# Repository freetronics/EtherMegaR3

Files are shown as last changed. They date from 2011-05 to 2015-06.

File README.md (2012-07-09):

Freetronics EtherMega R3
========================
Copyright 2011-2012 Freetronics Pty Ltd  
Freetronics site:  www.freetronics.com  
Freetronics email: info@freetronics.com  

The EtherMega R3 is a 100% Arduino-compatible board based on the existing
Mega2560, but with improvements and updates for features and ease of
use. It also includes on-board Ethernet with PoE (Power-over-Ethernet)
support.

Features:

 * High-efficiency switchmode power supply (input voltage 7-28Vdc)
 * Micro-USB Connector
 * microSD card slot
 * 10/100 Ethernet using the Wiznet W5100 chip
 * Overlay guide where you need it (both top and bottom)
 * D13 pin works for everything

You can view more at our product page at:

  http://www.freetronics.com/ethermega

INSTALLATION
------------
The design is saved as an EAGLE project. EAGLE PCB design software is
available from www.cadsoftusa.com free for non-commercial use. To use
this project download it and place the directory containing these files
into the "eagle" directory on your computer. Then open EAGLE and
navigate to Projects -> eagle -> EtherMegaR3.

DISTRIBUTION
------------
The specific terms of distribution of this project are governed by the
license referenced below.

LICENSE
-------
This work is licensed under the
Creative Commons Attribution-Share Alike License.  
To view a copy of this license, visit

  http://creativecommons.org/licenses/by-sa/3.0/  
  http://creativecommons.org/licenses/by-sa/3.0/legalcode

or send a letter to

  Creative Commons  
  171 Second Street, Suite 300  
  San Francisco  
  California, 94105  
  USA

The "license" folder within this repository also contains copies of the
licences referenced above.

CREDITS
-------
The EtherMega was designed by Marc Alexander (marc@freetronics.com) and
Jonathan Oxer (jon@freetronics.com) based on previous work by the Arduino
team (www.arduino.cc/playground/Main/People) which includes:

 * Massimo Banzi
 * David Cuartielles
 * Tom Igoe
 * Gianluca Martino
 * David A. Mellis

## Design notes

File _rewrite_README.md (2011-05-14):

Freetronics EtherTen
====================
Copyright 2010 Freetronics Pty Ltd  
Freetronics site:  <www.freetronics.com>  
Freetronics email: <info@freetronics.com>  

The EtherTen is a 100% Arduino Compatible Board, based on the existing
Duemilanove, but with improvements and updates for ease of use, cost
and getting started. It also includes on-board Ethernet with PoE (Power
-over-Ethernet) support.

Features:

 * LEDs visible on the edge
 * Mini-USB Connector
 * Overlay guide where you need it (both top and bottom)
 * D13 pin works for everything
 * RX pin biased
 * Mounting holes, power and X3 pads
 * All connections in the same place

You can view more at our product page at:

  http://www.freetronics.com/etherten

The "docs" folder within this repository includes a handy copy of the
schematic in PDF format, images of the pcb, and our Getting Started
guide that ships with each board.

INSTALLATION
------------
The design is saved as an EAGLE project. EAGLE PCB design software is
available from www.cadsoftusa.com free for non-commercial use. To use
this project download it and place the directory containing these files
into the "eagle" directory on your computer. Then open EAGLE and
navigate to Projects -> eagle -> EtherTen.

DISTRIBUTION
------------
The specific terms of distribution of this project are governed by the
license referenced below.

LICENSE
-------
This work is licensed under the
Creative Commons Attribution-Share Alike License.  
To view a copy of this license, visit

  http://creativecommons.org/licenses/by-sa/3.0/  
  http://creativecommons.org/licenses/by-sa/3.0/legalcode

or send a letter to

  Creative Commons  
  171 Second Street, Suite 300  
  San Francisco  
  California, 94105  
  USA

The "license" folder within this repository also contains copies of the
licences referenced above.

CREDITS
-------
The EtherTen was designed by Marc Alexander (marc@freetronics.com)
based on previous work by the Arduino team
(www.arduino.cc/playground/Main/People) which includes:

 * Massimo Banzi
 * David Cuartielles
 * Tom Igoe
 * Gianluca Martino
 * David A. Mellis

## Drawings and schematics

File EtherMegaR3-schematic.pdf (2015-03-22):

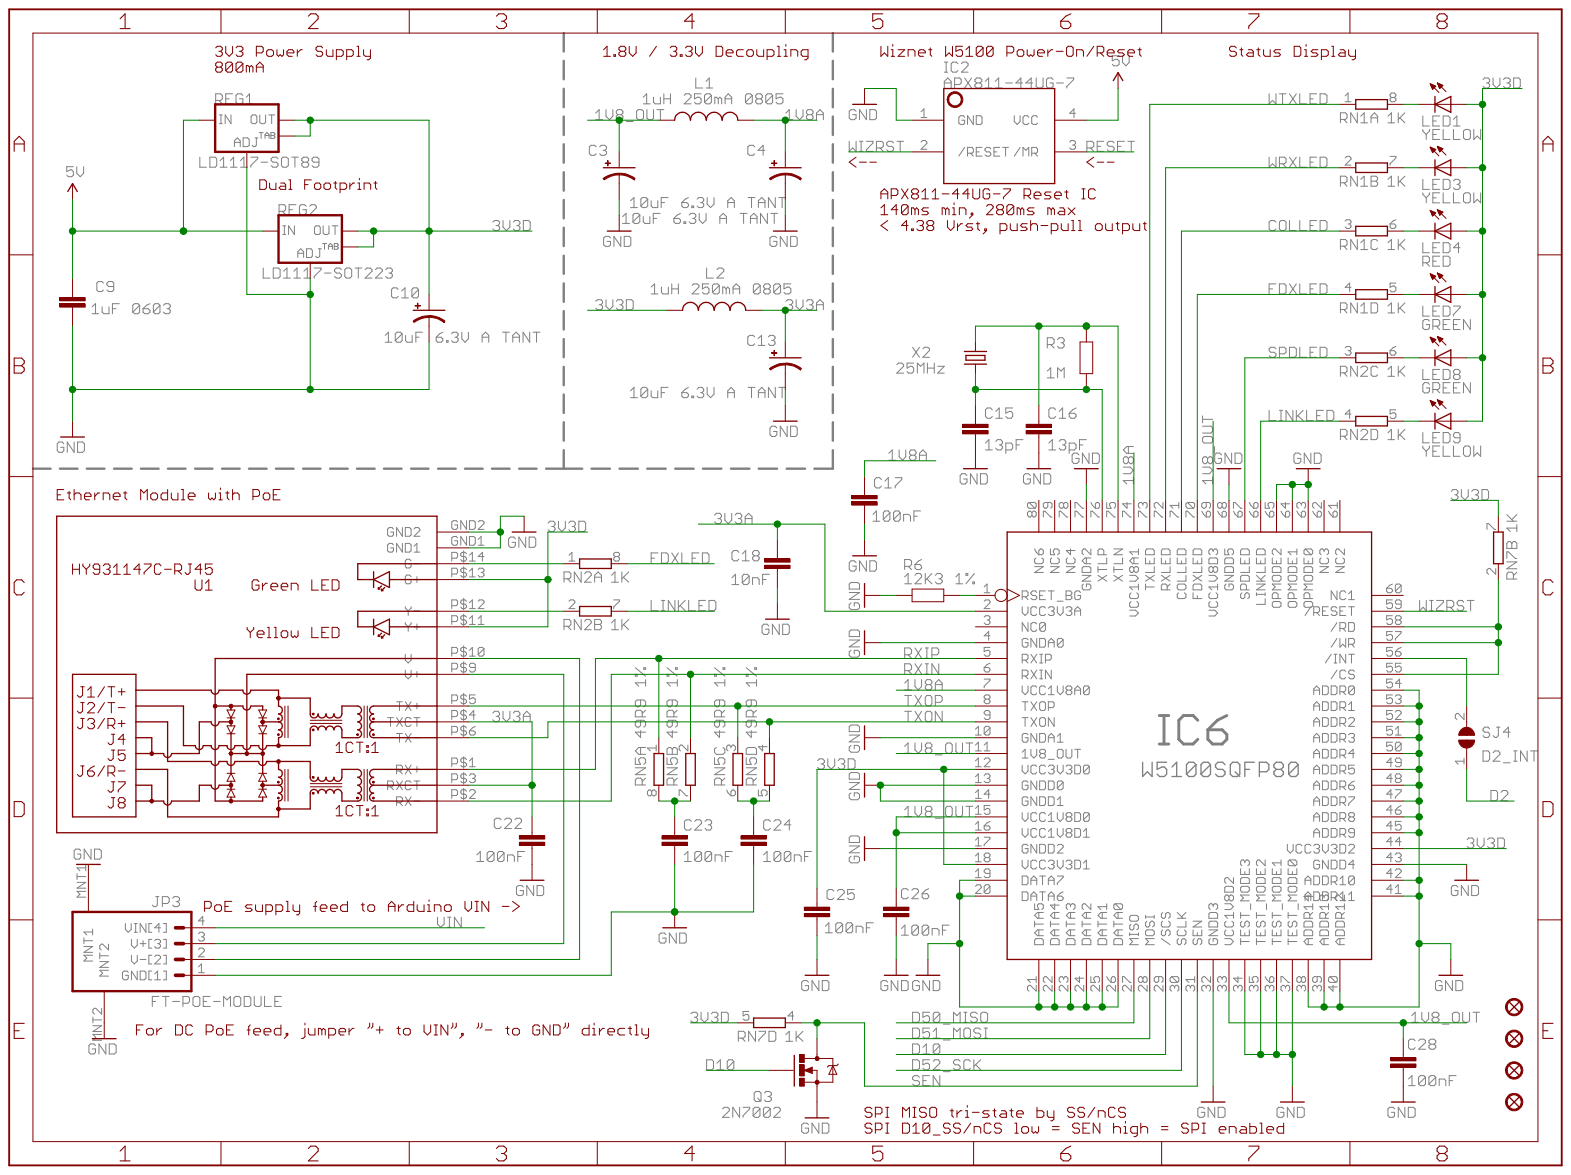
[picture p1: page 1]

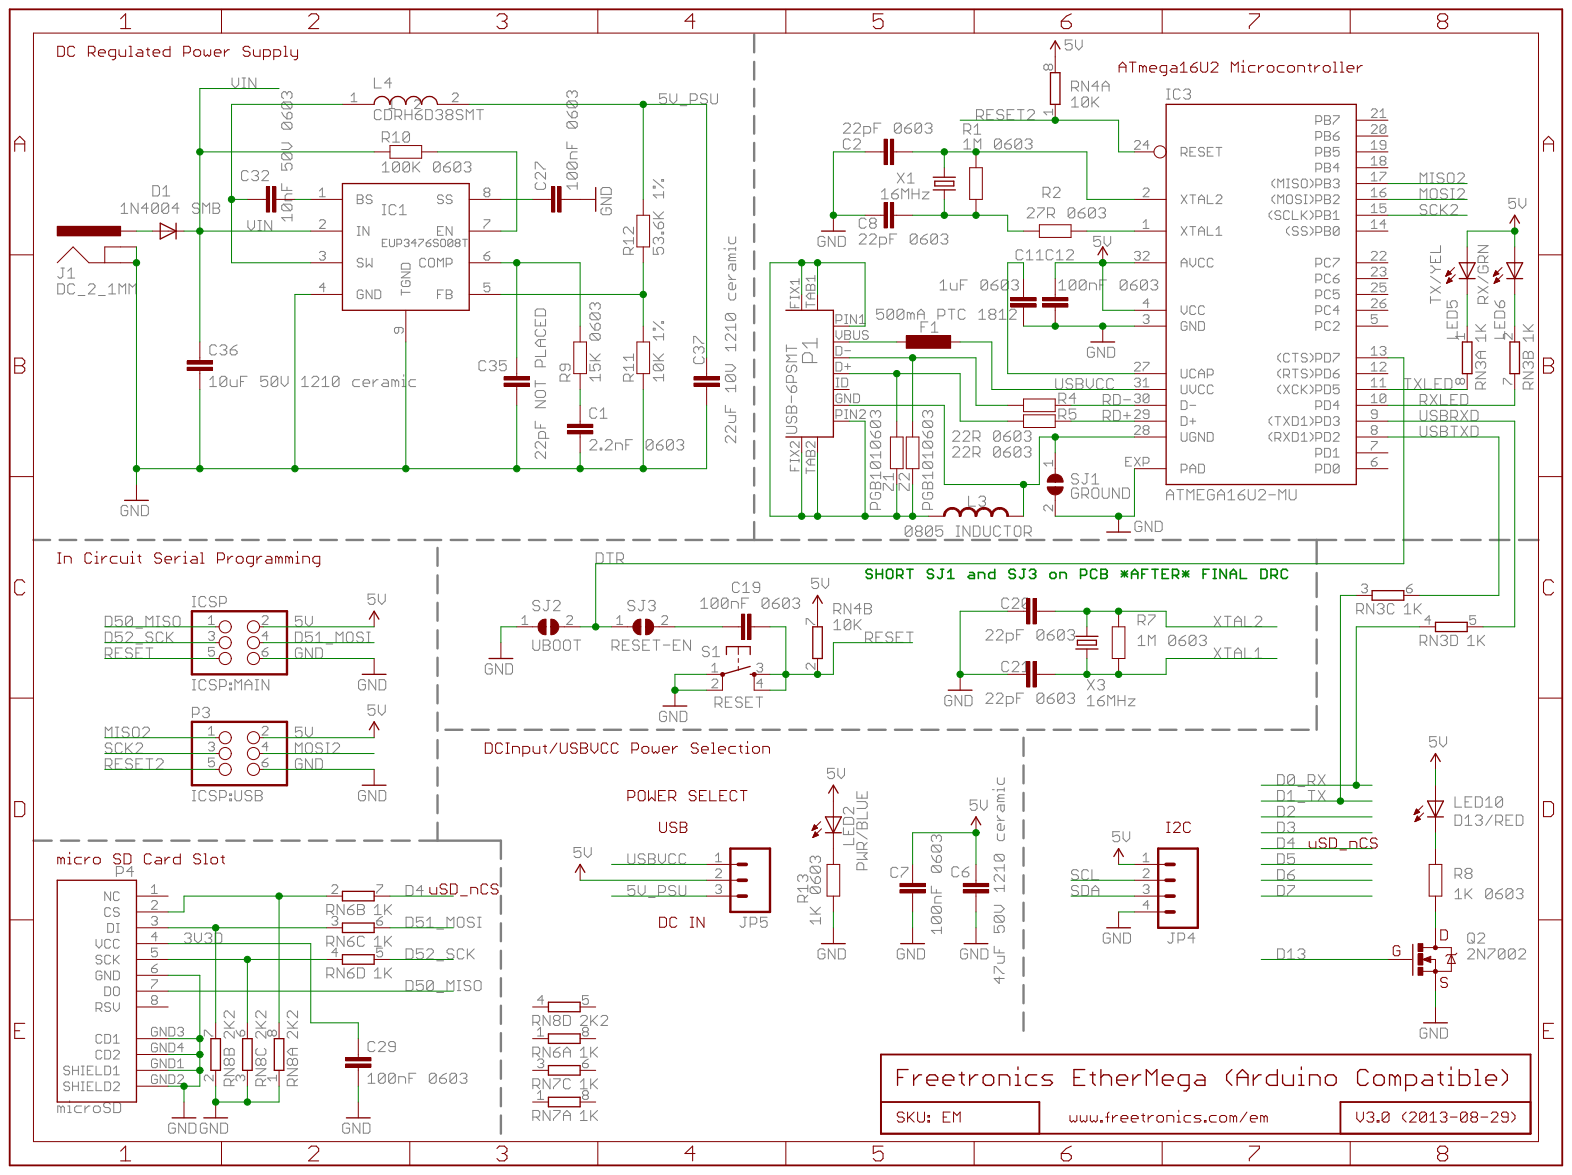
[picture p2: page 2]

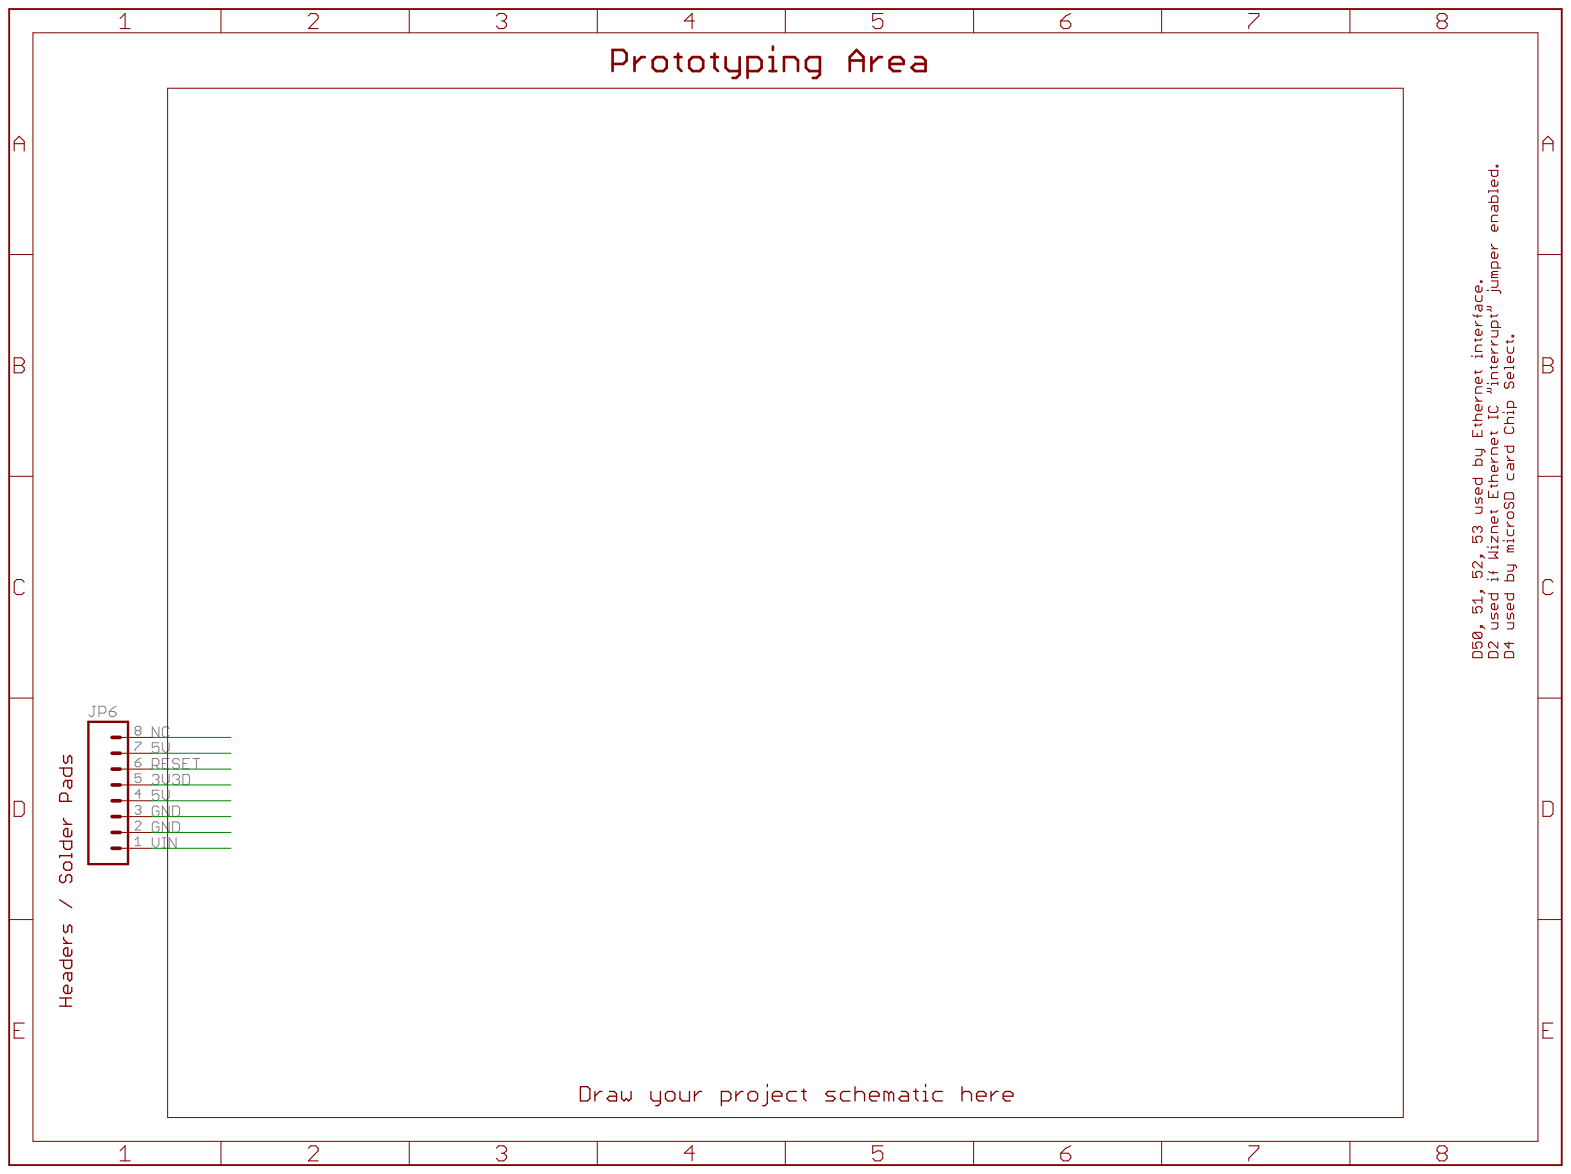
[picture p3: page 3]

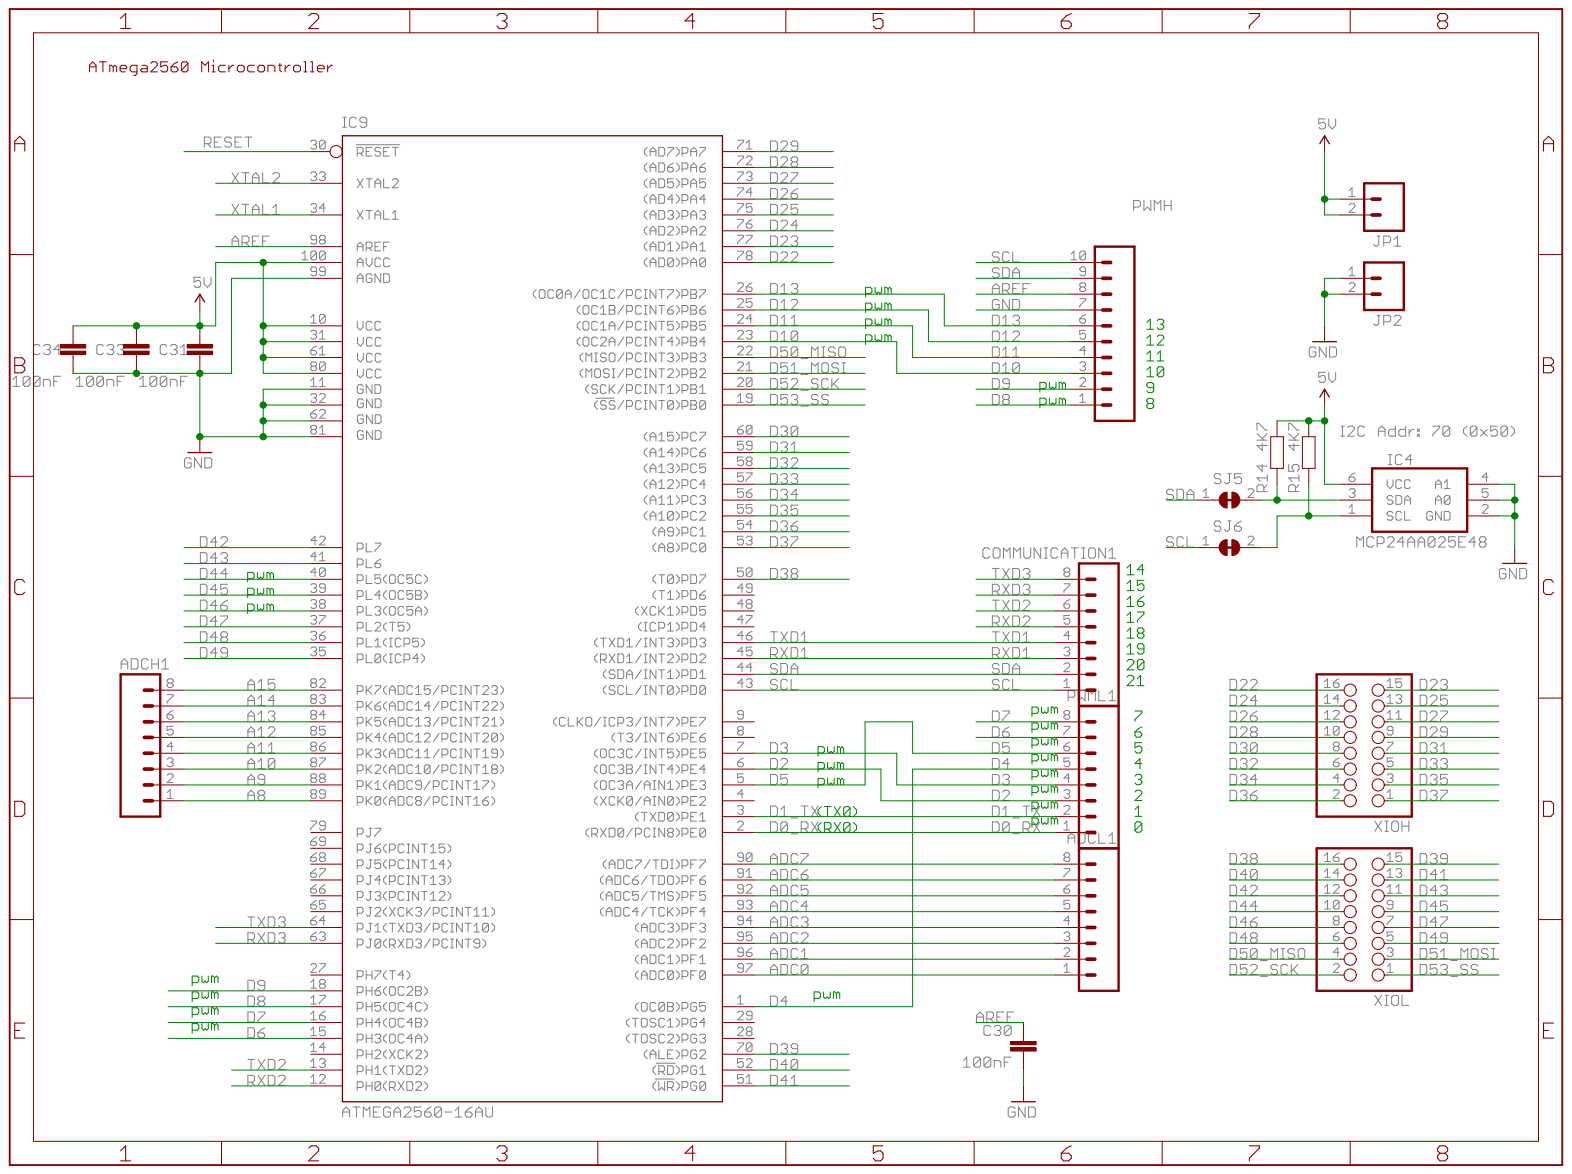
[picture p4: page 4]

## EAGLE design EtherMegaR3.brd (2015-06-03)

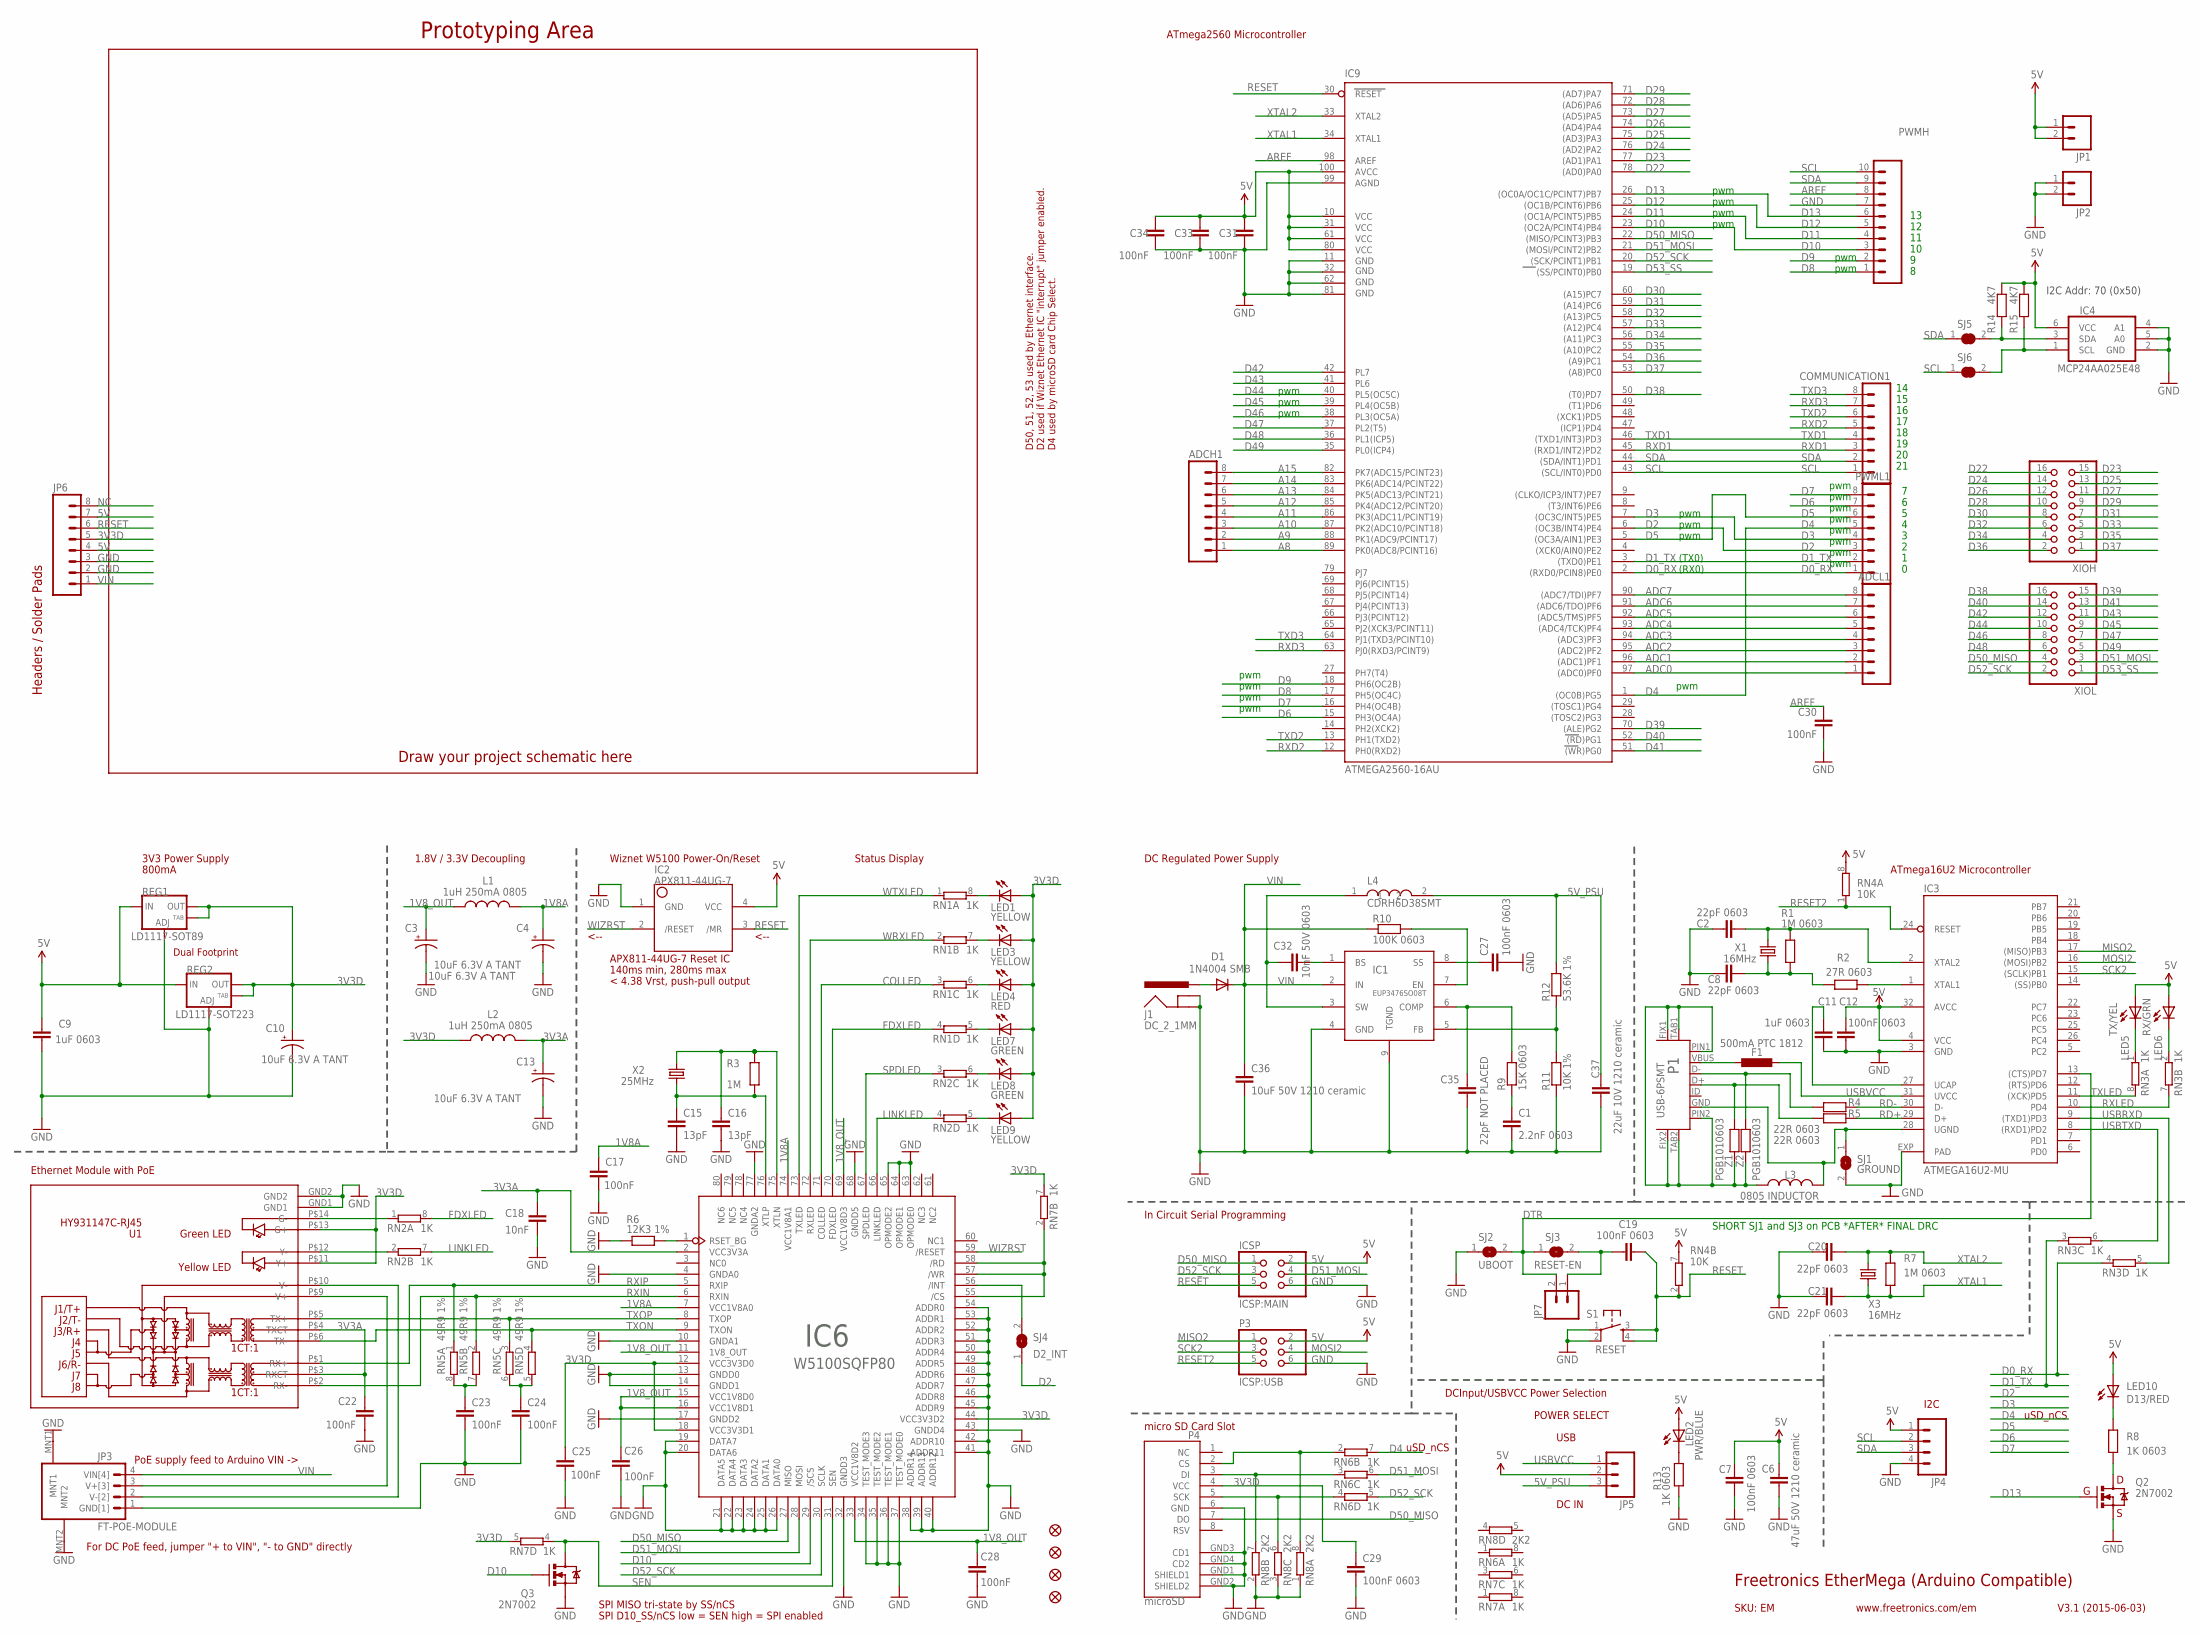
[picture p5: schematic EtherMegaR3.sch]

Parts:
ADCH1: M08STD; 1X08
ADCL1: M08STD; 1X08
C1: 2.2nF 0603; 0603
C2, C8, C20, C21: 22pF 0603; 0603
C3, C4, C10, C13: 10uF 6.3V A TANT; EIA3216
C6: 47uF 50V 1210 ceramic; C1210
C7, C12, C19, C27, C29: 100nF 0603; 0603
C9, C11: 1uF 0603; 0603
C15, C16: 13pF; 0603
C17, C22, C23, C24, C25, C26, C28, C30, C31, C33, C34: 100nF; 0603
C18: 10nF; 0603
C32: 10nF 50V 0603; 0603
C35: 22pF NOT PLACED; 0603
C36: 10uF 50V 1210 ceramic; C1210
C37: 22uF 10V 1210 ceramic; C1210
COMMUNICATION1: M08STD; 1X08
D1: 1N4004 SMB; SMB-DIODE
F1: 500mA PTC 1812; L1812
FID1, FID2, FID3, FID4: FIDUCIAL1X2.5; FIDUCIAL-1X2.5
IC1: EUP3476SO08T; SO08T
IC2: APX811-44UG-7; SOT143-R
IC3: ATMEGA16U2-MU; ATMEL_QFN32
IC4: MCP24AA025E48; SOT23-6
IC6: W5100SQFP80; SQFP80
IC9: ATMEGA2560-16AU; TQFP100
ICSP: ICSP:MAIN; 2X03
J1: DC_2_1MM; POWER_JACK_PTH
JP1, JP2, JP7: M02PTH; 1X02
JP3: FT-POE-MODULE; FT-POE-MODULE-CLEAN
JP4: M04PTH; 1X04
JP5: M03PTH; 1X03
JP6: M08STD; 1X08
L1, L2: 1uH 250mA 0805; L2012C
L3: 0805 INDUCTOR; 0805-LARGE
L4: CDRH6D38SMT; CDRH
LED1, LED3, LED9: YELLOW; LED-0603
LED2: PWR/BLUE; LED-0603
LED4: RED; LED-0603
LED5: TX/YEL; LED-0603
LED6: RX/GRN; LED-0603
LED7, LED8: GREEN; LED-0603
LED10: D13/RED; LED-0603
P1: USB-6PSMT; USB-MICROB-MB05PMXX
P3: ICSP:USB; 2X03
P4: microSD; MOLEX-SD-500901-003
PWMH: M100.1; 1X10
PWML1: M08STD; 1X08
Q2, Q3: 2N7002; SOT23-3
R1, R7: 1M 0603; 0603
R2: 27R 0603; 0603
R3: 1M; 0603
R4, R5: 22R 0603; 0603
R6: 12K3 1%; 0603
R8, R13: 1K 0603; 0603
R9: 15K 0603; 0603
R10: 100K 0603; 0603
R11: 10K 1%; 0603
R12: 53.6K 1%; 0603
R14, R15: 4K7; 0603
REG1: LD1117-SOT89; SOT89
REG2: LD1117-SOT223; SOT223
RN1, RN2, RN3, RN6, RN7: 1K; CAY16
RN4: 10K; CAY16
RN5: 49R9 1%; CAY16
RN8: 2K2; CAY16
S1: RESET; TACTILE_SWITCH_SMD
SJ1: GROUND; SJ
SJ2: UBOOT; SJ
SJ3: RESET-EN; SJ
SJ4: D2_INT; SJ
SJ5, SJ6: SJCN; SJC
U1: HY931147C-RJ45; HY931147C
X1, X3: 16MHz; HC49U-V
X2: 25MHz; HC49U-V
XIOH: PINHD-2X8; 2X08
XIOL: PINHD-2X8; 2X08
Z1, Z2: PGB1010603; 0603

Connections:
1V8A: C4.A (+), C17.1, IC6.7 (VCC1V8A0), IC6.74 (VCC1V8A1), L1.2
1V8_OUT: C3.A (+), C26.1, C28.1, IC6.11 (1V8_OUT), IC6.15 (VCC1V8D0), IC6.16 (VCC1V8D1), IC6.33 (VCC1V8D2), IC6.69 (VCC1V8D3), L1.1
3V3A: C13.A (+), C18.1, C22.1, IC6.2 (VCC3V3A), L2.2, U1.P$3 (RXCT), U1.P$4 (TXCT)
3V3D: C10.A (+), C25.1, C29.1, IC6.12 (VCC3V3D0), IC6.18 (VCC3V3D1), IC6.44 (VCC3V3D2), JP6.5, L2.1, LED1.A, LED3.A, LED4.A, LED7.A, LED8.A, LED9.A, P4.4 (VCC), REG1.2 (OUT), REG1.4 (OUT), REG2.2 (OUT), REG2.4 (OUT), RN7.5 (2), RN7.7 (2), U1.P$11 (Y+), U1.P$13 (G+)
5V: C6.2, C7.1, C9.1, C12.1, C31.1, C33.1, C34.1, IC2.4 (VCC), IC3.4 (VCC), IC3.32 (AVCC), IC4.6 (VCC), IC9.10 (VCC), IC9.31 (VCC1), IC9.61 (VCC2), IC9.80 (VCC3), IC9.100 (AVCC), ICSP.2, JP1.1, JP1.2, JP4.1, JP5.2, JP6.4, JP6.7, LED2.A, LED5.A, LED6.A, LED10.A, P3.2, R14.1, R15.1, REG1.3 (IN), REG2.3 (IN), RN4.7 (2), RN4.8 (2)
5V_PSU: C37.1, JP5.3, L4.2, R12.2
A8: ADCH1.1, IC9.89 (PK0(ADC8/PCINT16))
A9: ADCH1.2, IC9.88 (PK1(ADC9/PCINT17))
A10: ADCH1.3, IC9.87 (PK2(ADC10/PCINT18))
A11: ADCH1.4, IC9.86 (PK3(ADC11/PCINT19))
A12: ADCH1.5, IC9.85 (PK4(ADC12/PCINT20))
A13: ADCH1.6, IC9.84 (PK5(ADC13/PCINT21))
A14: ADCH1.7, IC9.83 (PK6(ADC14/PCINT22))
A15: ADCH1.8, IC9.82 (PK7(ADC15/PCINT23))
ADC0: ADCL1.1, IC9.97 ((ADC0)PF0)
ADC1: ADCL1.2, IC9.96 ((ADC1)PF1)
ADC2: ADCL1.3, IC9.95 ((ADC2)PF2)
ADC3: ADCL1.4, IC9.94 ((ADC3)PF3)
ADC4: ADCL1.5, IC9.93 ((ADC4/TCK)PF4)
ADC5: ADCL1.6, IC9.92 ((ADC5/TMS)PF5)
ADC6: ADCL1.7, IC9.91 ((ADC6/TDO)PF6)
ADC7: ADCL1.8, IC9.90 ((ADC7/TDI)PF7)
AREF: C30.1, IC9.98 (AREF), PWMH.8
COLLED: IC6.71 (COLLED), RN1.3 (1)
D0_RX: IC9.2 ((RXD0/PCIN8)PE0), PWML1.1, RN3.4 (1)
D1_TX: IC9.3 ((TXD0)PE1), PWML1.2, RN3.3 (1)
D2: IC9.6 ((OC3B/INT4)PE4), PWML1.3, SJ4.1
D3: IC9.7 ((OC3C/INT5)PE5), PWML1.4
D4: IC9.1 ((OC0B)PG5), PWML1.5, RN6.7 (2)
D5: IC9.5 ((OC3A/AIN1)PE3), PWML1.6
D6: IC9.15 (PH3(OC4A)), PWML1.7
D7: IC9.16 (PH4(OC4B)), PWML1.8
D8: IC9.17 (PH5(OC4C)), PWMH.1
D9: IC9.18 (PH6(OC2B)), PWMH.2
D10: IC6.29 (/SCS), IC9.23 ((OC2A/PCINT4)PB4), PWMH.3, Q3.1 (G)
D11: IC9.24 ((OC1A/PCINT5)PB5), PWMH.4
D12: IC9.25 ((OC1B/PCINT6)PB6), PWMH.5
D13: IC9.26 ((OC0A/OC1C/PCINT7)PB7), PWMH.6, Q2.1 (G)
D22: IC9.78 ((AD0)PA0), XIOH.16
D23: IC9.77 ((AD1)PA1), XIOH.15
D24: IC9.76 ((AD2)PA2), XIOH.14
D25: IC9.75 ((AD3)PA3), XIOH.13
D26: IC9.74 ((AD4)PA4), XIOH.12
D27: IC9.73 ((AD5)PA5), XIOH.11
D28: IC9.72 ((AD6)PA6), XIOH.10
D29: IC9.71 ((AD7)PA7), XIOH.9
D30: IC9.60 ((A15)PC7), XIOH.8
D31: IC9.59 ((A14)PC6), XIOH.7
D32: IC9.58 ((A13)PC5), XIOH.6
D33: IC9.57 ((A12)PC4), XIOH.5
D34: IC9.56 ((A11)PC3), XIOH.4
D35: IC9.55 ((A10)PC2), XIOH.3
D36: IC9.54 ((A9)PC1), XIOH.2
D37: IC9.53 ((A8)PC0), XIOH.1
D38: IC9.50 ((T0)PD7), XIOL.16
D39: IC9.70 ((ALE)PG2), XIOL.15
D40: IC9.52 ((RD)PG1), XIOL.14
D41: IC9.51 ((WR)PG0), XIOL.13
D42: IC9.42 (PL7), XIOL.12
D43: IC9.41 (PL6), XIOL.11
D44: IC9.40 (PL5(OC5C)), XIOL.10
D45: IC9.39 (PL4(OC5B)), XIOL.9
D46: IC9.38 (PL3(OC5A)), XIOL.8
D47: IC9.37 (PL2(T5)), XIOL.7
D48: IC9.36 (PL1(ICP5)), XIOL.6
D49: IC9.35 (PL0(ICP4)), XIOL.5
D50_MISO: IC6.27 (MISO), IC9.22 ((MISO/PCINT3)PB3), ICSP.1, P4.7 (DO), XIOL.4
D51_MOSI: IC6.28 (MOSI), IC9.21 ((MOSI/PCINT2)PB2), ICSP.4, RN6.6 (2), XIOL.3
D52_SCK: IC6.30 (SCLK), IC9.20 ((SCK/PCINT1)PB1), ICSP.3, RN6.5 (2), XIOL.2
D53_SS: IC9.19 ((SS/PCINT0)PB0), XIOL.1
DTR: IC3.13 ((CTS)PD7), JP7.2, SJ2.2, SJ3.1
FDXLED: IC6.70 (FDXLED), RN1.4 (1), RN2.8 (2)
GND: C1.2, C2.1, C3.C (-), C4.C (-), C6.1, C7.2, C8.1, C9.2, C10.C (-), C11.2, C12.2, C13.C (-), C15.2, C16.2, C17.2, C18.2, C20.1, C21.1, C22.2, C23.2, C24.2, C25.2, C26.2, C27.2, C28.2, C29.2, C30.2, C31.2, C33.2, C34.2, C35.2, C36.2, C37.2, IC1.4 (GND), IC1.9 (TGND), IC2.1 (GND), IC3.3 (GND), IC3.EXP (PAD), IC4.2 (GND), IC4.4 (A1), IC4.5 (A0), IC6.4 (GNDA0), IC6.10 (GNDA1), IC6.13 (GNDD0), IC6.14 (GNDD1), IC6.17 (GNDD2), IC6.19 (DATA7), IC6.20 (DATA6), IC6.21 (DATA5), IC6.22 (DATA4), IC6.23 (DATA3), IC6.24 (DATA2), IC6.25 (DATA1), IC6.26 (DATA0), IC6.32 (GNDD3), IC6.34 (TEST_MODE3), IC6.35 (TEST_MODE2), IC6.36 (TEST_MODE1), IC6.37 (TEST_MODE0), IC6.38 (ADDR14), IC6.39 (ADDR13), IC6.40 (ADDR12), IC6.41 (ADDR11), IC6.42 (ADDR10), IC6.43 (GNDD4), IC6.45 (ADDR9), IC6.46 (ADDR8), IC6.47 (ADDR7), IC6.48 (ADDR6), IC6.49 (ADDR5), IC6.50 (ADDR4), IC6.51 (ADDR3), IC6.52 (ADDR2), IC6.53 (ADDR1), IC6.54 (ADDR0), IC6.63 (OPMODE0), IC6.64 (OPMODE1), IC6.65 (OPMODE2), IC6.68 (GNDD5), IC6.77 (GNDA2), IC9.11 (GND), IC9.32 (GND1), IC9.62 (GND2), IC9.81 (GND3), IC9.99 (AGND), ICSP.6, J1.GND, J1.GNDBREAK, JP2.1, JP2.2, JP3.1 (GND[1]), JP3.MNT1, JP3.MNT2, JP4.4, JP6.2, JP6.3, P3.6, P4.6 (GND), P4.GND1 (SHIELD1), P4.GND2 (SHIELD2), P4.GND3 (CD1), P4.GND4 (CD2), PWMH.7, Q2.2 (S), Q3.2 (S), R6.1, R11.1, R13.1, REG1.1 (ADJ), REG2.1 (ADJ), RN8.1, RN8.2 (1), RN8.3 (1), S1.1, S1.2, SJ1.2, SJ2.1, U1.GND1, U1.GND2
LINKLED: IC6.66 (LINKLED), RN2.4 (1), RN2.7 (2)
MISO2: IC3.17 ((MISO)PB3), P3.1
MOSI2: IC3.16 ((MOSI)PB2), P3.4
unnamed: C24.1, RN5.5 (2), RN5.6 (2)
unnamed: LED10.C, R8.2
unnamed: Q2.3 (D), R8.1
unnamed: IC3.1 (XTAL1), R2.1
unnamed: IC4.1 (SCL), R15.2, SJ6.2
unnamed: LED6.C, RN3.2 (1)
unnamed: LED2.C, R13.2
unnamed: LED5.C, RN3.1
unnamed: P1.D+, R5.2, Z1.1
unnamed: P1.D-, R4.2, Z2.1
unnamed: L3.1, P1.FIX1, P1.FIX2, P1.PIN1, P1.PIN2, P1.TAB1, P1.TAB2, Z1.2, Z2.2
unnamed: IC4.3 (SDA), R14.2, SJ5.2
unnamed: P4.5 (SCK), RN6.4 (1), RN8.6 (2)
unnamed: P4.2 (CS), RN6.2 (1), RN8.8 (2)
unnamed: P4.3 (DI), RN6.3 (1), RN8.7 (2)
unnamed: LED8.C, RN2.6 (2)
unnamed: IC6.55 (/CS), IC6.57 (/WR), IC6.58 (/RD), RN7.2 (1)
unnamed: LED9.C, RN2.5 (2)
unnamed: D1.A, J1.PWR
unnamed: IC6.56 (/INT), SJ4.2
unnamed: C27.1, IC1.8 (SS)
unnamed: C1.1, R9.1
unnamed: C35.1, IC1.6 (COMP), R9.2
unnamed: RN2.1, U1.P$14 (G-)
unnamed: JP3.3 (V+[3]), U1.P$9 (V+)
unnamed: JP3.2 (V-[2]), U1.P$10 (V-)
unnamed: C32.1, IC1.3 (SW), L4.1
unnamed: C32.2, IC1.1 (BS)
unnamed: IC1.7 (EN), R10.2
unnamed: IC3.28 (UGND), L3.2, P1.GND, SJ1.1
unnamed: C19.1, JP7.1, SJ3.2
unnamed: IC1.5 (FB), R11.2, R12.1
unnamed: C2.2, IC3.2 (XTAL2), R1.2, X1.2
unnamed: C8.2, R1.1, R2.2, X1.1
unnamed: F1.1, P1.VBUS
unnamed: C11.1, IC3.27 (UCAP)
unnamed: C23.1, RN5.7 (2), RN5.8 (2)
unnamed: IC6.1 (RSET_BG), R6.2
unnamed: LED7.C, RN1.5 (2)
unnamed: LED4.C, RN1.6 (2)
unnamed: LED3.C, RN1.7 (2)
unnamed: LED1.C, RN1.8 (2)
unnamed: RN2.2 (1), U1.P$12 (Y-)
NC: JP6.8
RD+: IC3.29 (D+), R5.1
RD-: IC3.30 (D-), R4.1
RESET: C19.2, IC2.3 (/MR), IC9.30 (RESET), ICSP.5, JP6.6, RN4.2 (1), S1.3, S1.4
RESET2: IC3.24 (RESET), P3.5, RN4.1
RXD1: COMMUNICATION1.3, IC9.45 ((RXD1/INT2)PD2)
RXD2: COMMUNICATION1.5, IC9.12 (PH0(RXD2))
RXD3: COMMUNICATION1.7, IC9.63 (PJ0(RXD3/PCINT9))
RXIN: IC6.6 (RXIN), RN5.2 (1), U1.P$2 (RX-)
RXIP: IC6.5 (RXIP), RN5.1, U1.P$1 (RX+)
RXLED: IC3.10 (PD4), RN3.7 (2)
SCK2: IC3.15 ((SCLK)PB1), P3.3
SCL: COMMUNICATION1.1, IC9.43 ((SCL/INT0)PD0), JP4.2, PWMH.10, SJ6.1
SDA: COMMUNICATION1.2, IC9.44 ((SDA/INT1)PD1), JP4.3, PWMH.9, SJ5.1
SEN: IC6.31 (SEN), Q3.3 (D), RN7.4 (1)
SPDLED: IC6.67 (SPDLED), RN2.3 (1)
TXD1: COMMUNICATION1.4, IC9.46 ((TXD1/INT3)PD3)
TXD2: COMMUNICATION1.6, IC9.13 (PH1(TXD2))
TXD3: COMMUNICATION1.8, IC9.64 (PJ1(TXD3/PCINT10))
TXLED: IC3.11 ((XCK)PD5), RN3.8 (2)
TXON: IC6.9 (TXON), RN5.4 (1), U1.P$6 (TX-)
TXOP: IC6.8 (TXOP), RN5.3 (1), U1.P$5 (TX+)
USBRXD: IC3.9 ((TXD1)PD3), RN3.5 (2)
USBTXD: IC3.8 ((RXD1)PD2), RN3.6 (2)
USBVCC: F1.2, IC3.31 (UVCC), JP5.1
VIN: C36.1, D1.C, IC1.2 (IN), JP3.4 (VIN[4]), JP6.1, R10.1
WIZRST: IC2.2 (/RESET), IC6.59 (/RESET)
WRXLED: IC6.72 (RXLED), RN1.2 (1)
WTXLED: IC6.73 (TXLED), RN1.1
XTAL1: C21.2, IC9.34 (XTAL1), R7.1, X3.1
XTAL2: C20.2, IC9.33 (XTAL2), R7.2, X3.2
XTLN: C16.1, IC6.75 (XTLN), R3.2, X2.2
XTLP: C15.1, IC6.76 (XTLP), R3.1, X2.1

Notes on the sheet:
Prototyping Area
3V3 Power Supply
Status Display
Headers / Solder Pads
Dual Footprint
1.8V / 3.3V Decoupling
Draw your project schematic here
D50, 51, 52, 53 used by Ethernet interface.
D2 used if Wiznet Ethernet IC "interrupt" jumper enabled.
PoE supply feed to Arduino VIN ->
SPI MISO tri-state by SS/nCS
SPI D10_SS/nCS low = SEN high = SPI enabled
For DC PoE feed, jumper "+ to VIN", "- to GND" directly
DC Regulated Power Supply
ATmega2560 Microcontroller
APX811-44UG-7 Reset IC
140ms min, 280ms max
ATmega16U2 Microcontroller
DCInput/USBVCC Power Selection
Wiznet W5100 Power-On/Reset
uSD_nCS
800mA
In Circuit Serial Programming
micro SD Card Slot
Freetronics EtherMega (Arduino Compatible)
V3.1 (2015-06-03)
www.freetronics.com/em
SKU: EM
Ethernet Module with PoE
< 4.38 Vrst, push-pull output
<--
D4 used by microSD card Chip Select.
pwm
(TX0)
(RX0)
SHORT SJ1 and SJ3 on PCB *AFTER* FINAL DRC
I2C
USB
DC IN
POWER SELECT

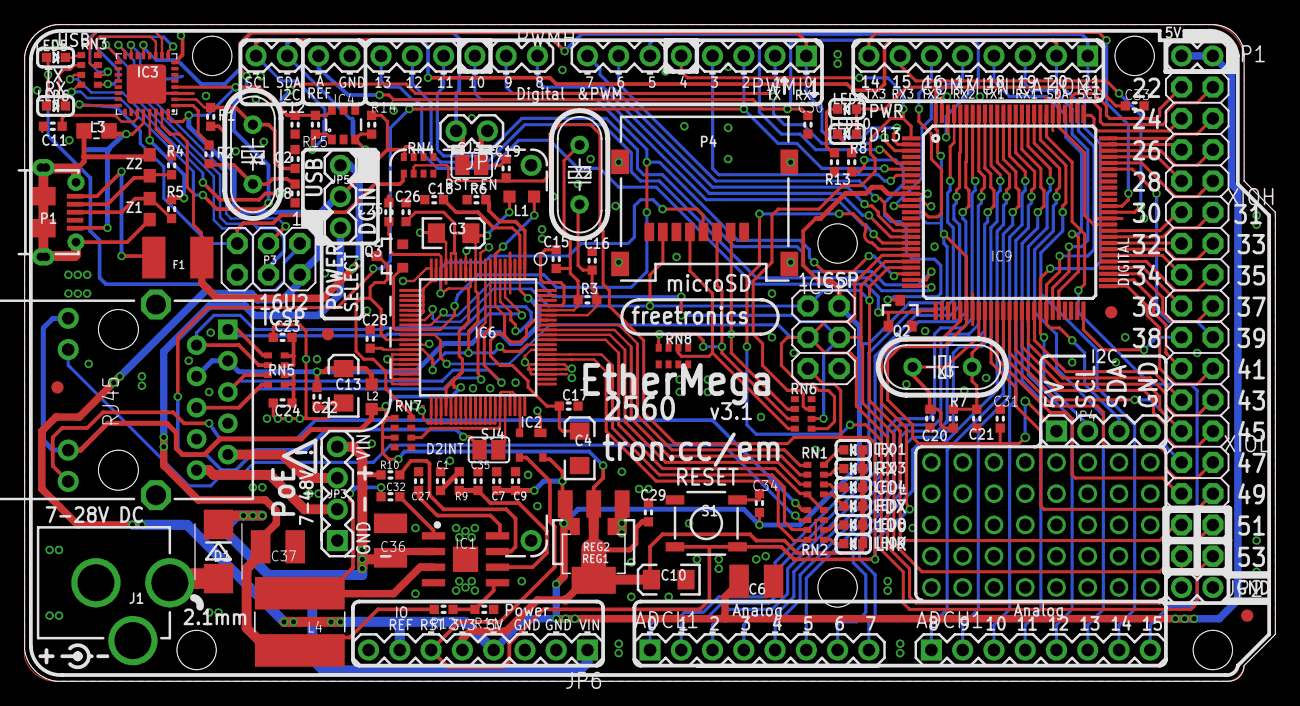
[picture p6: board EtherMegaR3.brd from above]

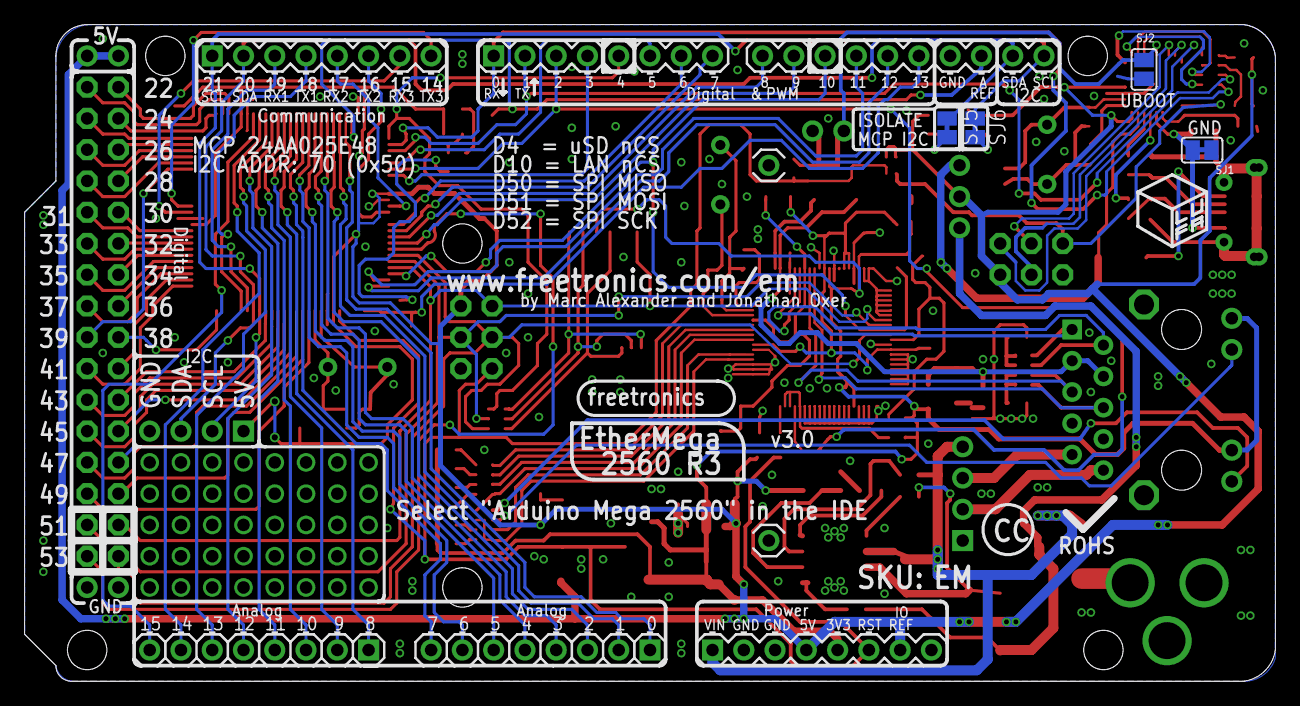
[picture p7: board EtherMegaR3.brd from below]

Board: 2 copper layers, 101.6 x 53.3 mm, 120 parts (4 on the bottom side), 151 nets.

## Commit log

2011-05-14 Initial project files
    [EtherMega.brd, EtherMega.sch]
2011-05-14 Cleaned up some net names
    [EtherMega.brd, EtherMega.sch]
2011-05-18 Updated net names; routing
    [EtherMega.brd, EtherMega.sch]
2011-05-28 Making a mess
    [EtherMega.brd]
2011-06-13 Pushin and shovin
    [EtherMega.brd]
2011-07-06 Fixed split SPI problem; more routing
    [EtherMega.brd, EtherMega.sch]
2011-07-12 Changed PWR LED dropper to 2k2; routing
    [EtherMega.brd, EtherMega.sch]
2011-07-18 Net name fix, SJ short-jumpers cleaned
    [EtherMega.brd, EtherMega.sch]
2011-07-24 Added I2C header, plus more routing
    [EtherMega.brd, EtherMega.sch]
2011-08-15 Started replacing linear reg with switcher
    [EtherMega.brd, EtherMega.sch]
2011-08-30 Replaced linear regulator with switcher
    [EtherMega.brd, EtherMega.sch]
2011-08-30 Minor schematic rearrangement
    [EtherMega.brd, EtherMega.sch]
2011-09-05 Routing switchmode supply
    [EtherMega.brd, EtherMega.sch]
2011-09-08 Routing updates
    [EtherMega.brd]
2011-09-09 Routing tweaks
    [EtherMega.brd, EtherMega.sch]
2011-09-12 Clearance adjustments
    [EtherMega.brd]
2011-09-16 Minor schematic cleanup
    [EtherMega.sch]
2011-09-16 DRC clearances
    [EtherMega.brd]
2011-09-17 Overlay and routing tweaks
    [EtherMega.brd]
2011-09-17 Silkscreen tweaks
    [EtherMega.brd]
2011-09-17 Shorted SJ1 and SJ3 for production
    [EtherMega.brd]
2011-09-17 Changed references to pins reserved for SPI
    [EtherMega.brd, EtherMega.sch]
2011-09-17 Tiny silkscreen fixes
    [EtherMega.brd]
2011-09-19 Improved part name placement
    [EtherMega.brd]
2011-10-04 Removed power autoswitcher
    [EtherMega.brd, EtherMega.sch]
2011-10-07 Jumper selection of power source
    [EtherMega.brd, EtherMega.sch]
2011-10-09 Jumper power source USBVCC in progress
    [EtherMega.brd, EtherMega.sch]
2011-10-09 USB and DC-IN power selection, DRC passed
    [EtherMega.brd, EtherMega.sch]
2011-10-10 Updated EUP3476 footprint
    [EtherMega.brd, EtherMega.sch]
2011-10-10 ERC's and power ports sorted out
    [EtherMega.brd, EtherMega.sch]
2011-10-11 v1.0 release!
    Tons'o'tweaks, All DRC's gone through, 8U2 GND fixed, Overlays, PWR LED R and cleanup
    [EtherMega.brd, EtherMega.sch]
2011-10-11 v1.0 release, C35 and R9 value revision
    [EtherMega.brd, EtherMega.sch]
2011-10-25 Changed Wiznet SS from D53 to D10
    [EtherMega.brd, EtherMega.sch]
2011-10-26 Minor overlay update for v1.1 release
    [EtherMega.brd]
2011-10-26 Overlay updates for v1.1 release
    [EtherMega.brd, EtherMega.sch]
2011-10-26 Changed R12 to 53K6 to fix vreg output
    [EtherMega.brd, EtherMega.sch]
2011-10-26 v1.1 production release
    [EtherMega.brd]
2012-07-09 Renamed files for R3 revision
    [EtherMegaR3.brd, EtherMegaR3.sch]
2012-07-09 Swapped headers
    [EtherMegaR3.brd, EtherMegaR3.sch]
2012-08-18 Changes for R3 release
    [EtherMegaR3.brd, EtherMegaR3.sch]
2013-08-29 Added MAC address chip and changed to hinge SD socket for v3.0 release
    [EtherMegaR3.brd, EtherMegaR3.sch]
2015-03-22 Added v3.0 schematic
2015-06-03 Added M02 header in parallel with RST-EN cut-track link for external reset mode control
    [EtherMegaR3.brd, EtherMegaR3.sch]
